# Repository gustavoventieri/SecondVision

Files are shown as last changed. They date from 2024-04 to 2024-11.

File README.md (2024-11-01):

<h1 align="center"> Second Vision </h1> <br>
<p align="center">
  <a href="https://github.com/gustavoventieri/SecondVision">
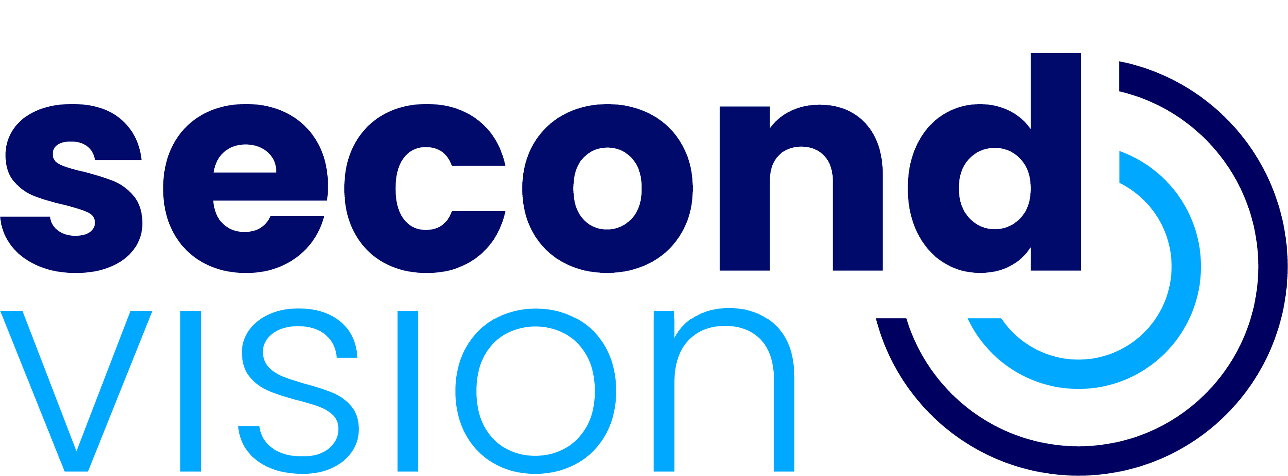
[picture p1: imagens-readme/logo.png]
Second Vision Logo GitPoint
    
  </a>
</p>

<p align="center">
  Second Vision, uma nova forma de enxergar o mundo para aqueles que não o podem ver.
</p>

## Tabela de Conteúdos

- [Introdução](#Introdução)
- [Documentação](#Documentação)
- [Desenvolvedores](#Desenvolvedores)

## Introdução

Este repositório contém o código e a documentação do Trabalho de Conclusão de Curso (TCC) dos alunos da ETEC da Zona Leste. Esse TCC consiste em um dispositivo de microcomputador projetado para auxiliar deficientes visuais na detecção de objetos potencialmente perigosos no ambiente metropolitano.

O dispositivo utiliza uma câmera integrada para capturar imagens do ambiente ao redor do usuário e, em seguida, processa essas imagens em tempo real para identificar objetos potencialmente perigosos, como obstáculos. Quando um objeto perigoso é detectado, o dispositivo emite alertas sonoros através de uma aplicação mobile para notificar o usuário sobre a presença do objeto.

O objetivo deste projeto é aumentar a autonomia e segurança das pessoas com deficiência visual em suas atividades diárias, proporcionando-lhes uma ferramenta acessível e eficaz para detectar e evitar obstáculos nas metrópoles.

## Documentação

Aqui estão alguns documentos construídos ao decorrer do trabalho: 

* Monografia
* Diagrama de Casos de Uso
* Diagrama de Máquina-Estado
* Diagrama de Sequência
* Diagrama de Atividade
* Wireframes
  
## Desenvolvedores

Obrigado pela dedicação e foco de todos os envolvidos!

# Autores
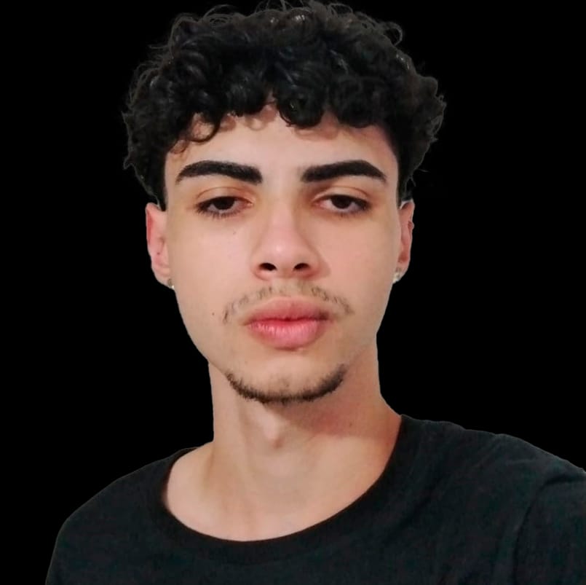
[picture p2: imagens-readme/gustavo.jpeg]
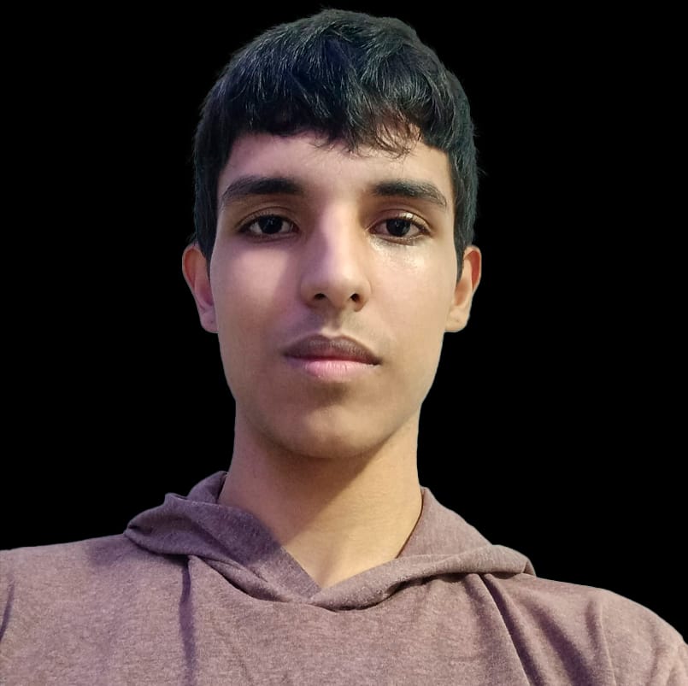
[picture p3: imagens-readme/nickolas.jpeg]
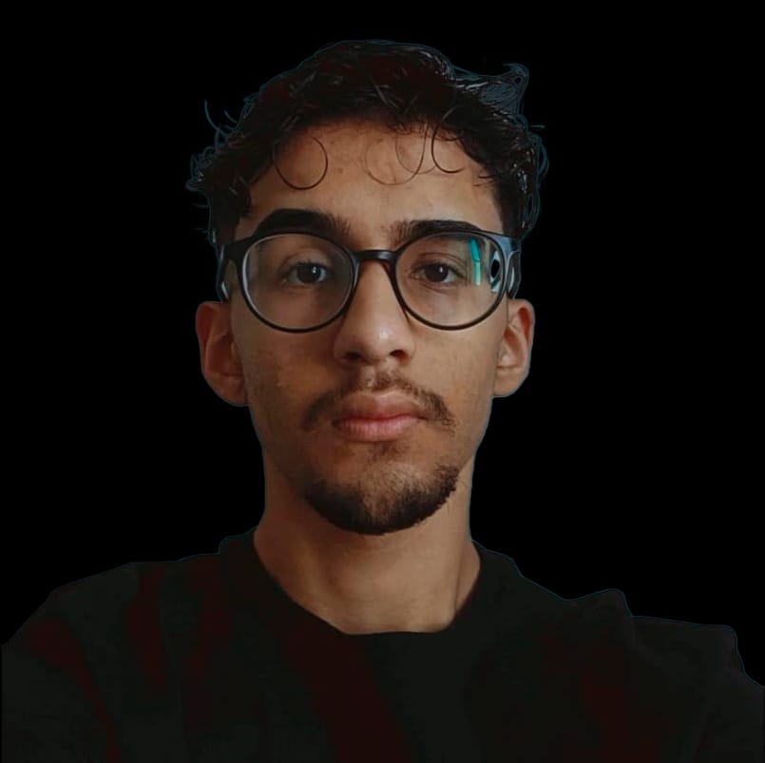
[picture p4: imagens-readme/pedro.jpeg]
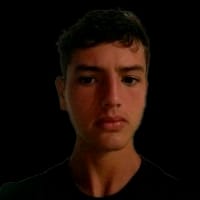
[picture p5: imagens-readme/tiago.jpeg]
| [<br><sub>Gustavo Mendes Ventieri Mariano</sub>](https://github.com/gustavoventieri/) |  [<br><sub>Nickolas Maia de Araujo</sub>](https://github.com/nickolss)  |  [<br><sub>Pedro Fernandes Araújo</sub>](https://github.com/PedroFAraujo) | [<br><sub>Tiago Bryan Ramos de Oliveira</sub>](https://github.com/TiagoBryan) | 
| :---: | :---: | :---: | :---: |

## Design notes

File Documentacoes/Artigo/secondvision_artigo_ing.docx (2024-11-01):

Second Vision - Sistema para auxílio de deficientes visuais

Second Vision - System to help the visually impaired

Second Vision - Sistema de ayuda a los discapacitados visuales

Gustavo Mendes Ventieri Mariano [^1]

ventierigustavo@gmail.com

Nickolas Maia de Araujo ¹

Nickolasmaraujo@gmail.com

Pedro Fernandes Araújo¹

pedrofeearaujo@gmail.com

Tiago Bryan Ramos de Oliveira ¹

tiagobryanroliveira@gmail.com

Jeferson Roberto de Lima¹

Jeferson.lima17@etec.sp.gov.br

Palavras-chave:

Sistema.

Autonomia.

Deficiência Visual.

Visão Computacional.

Keywords:

System.

Autonomy.

Visually Impaired.

Computer Vision.

Palabras clave:

Sistema.

Autonomía.

Discapacidad Visual.

Visión Por Ordenador.

Apresentado em:

05 dezembro, 2024

Evento:

7º EnGeTec

Local do evento:

Fatec Zona Leste

Avaliadores:

Avaliador 1

Avaliador 2

Resumo:

Este trabalho apresenta um sistema que auxilia a autonomia e inclusão de pessoas com deficiência visual. Por meio da tecnologia vestível e da visão computacional, o sistema oferece uma gama de funcionalidades que podem auxiliar a locomoção. O objetivo principal é promover a inclusão social e melhorar a qualidade de vida dessa parcela da população, que enfrenta sérios desafios e desigualdades, mesmo com os benefícios legais. A pesquisa foi baseada em estudo quali-quantitativo para identificar as principais dificuldades dos deficientes visuais. O sistema abarca um IoT para a captação de objetos possivelmente perigosos e textos em placas estáticas em um software para gerar a saída dessa detecção em áudio. Espera-se que o sistema proposto tenha um impacto positivo na vida dessas pessoas, reduzindo o número de acidentes, melhorando a saúde física, mental e autoestima, promovendo a inserção comunitária e, por fim, elevando a qualidade de vida. Conclui-se que, por meio desse trabalho, o público-alvo consiga uma melhora na condição de vida, beneficiando-se de um possível ganho de autonomia para atenuar a marginalização desse grupo.

Abstract:

This paper presents a system that aids the autonomy and inclusion of visually impaired people. Using wearable technology and computer vision, the system offers a range of functionalities that can help people get around. The main objective is to promote social inclusion and improve the quality of life of this section of the population, which faces serious challenges and inequalities, even with legal benefits. The research was based on a qualitative-quantitative study to identify the main difficulties faced by the visually impaired. The system includes an IoT to capture possibly dangerous objects and texts on static signs and software to generate audio output from this detection. It is hoped that the proposed system will have a positive impact on the lives of these people, reducing the number of accidents, improving their physical and mental health and self-esteem, promoting community integration, and, ultimately, raising their quality of life. It is concluded that, through this work, the target audience will achieve an improvement in their living conditions, benefiting from a possible gain in autonomy to mitigate the marginalization of this group.

Resumen:

Este trabajo presenta un sistema que ayuda a la autonomía e inclusión de personas con discapacidad visual. A través de tecnología wearable y visión por computador, el sistema ofrece una serie de funcionalidades que pueden ayudar a la locomoción. El objetivo principal es promover la inclusión social y mejorar la calidad de vida de este sector de la población, que se enfrenta a graves desafíos y desigualdades, incluso con beneficios legales. La investigación se basó en un estudio cualitativo-cuantitativo para identificar las principales dificultades a las que se enfrentan las personas con discapacidad visual. El sistema incluye un IOT para detectar objetos y textos posiblemente peligrosos en señales estáticas y un software para generar una salida de audio a partir de esta detección. Se espera que el sistema propuesto tenga un impacto positivo en la vida de estas personas, reduciendo el número de accidentes, mejorando su salud física y mental y su autoestima, promoviendo la integración en la comunidad y, en definitiva, aumentando su calidad de vida. Se concluye que, a través de este trabajo, el público objetivo conseguirá una mejora en sus condiciones de vida, beneficiándose de una posible ganancia de autonomía que mitigue la marginación de este colectivo.

# 1. Introduction

The visually impaired are all those with total or partial loss of sight, making up a significant portion of the Brazilian population (ALVES; DUARTE, 2008), approximately 8.9% of citizens (PNAD CONTÍNUA, 2022). As a result of this condition, they face psychological, social and economic problems, resulting in loss of self-esteem, status, occupational restrictions and reduced income (FILHO, 2012). As a result, this study aims to restore some of the autonomy of the visually impaired, provide a comprehensive form of personal prevention and improve the psychological and economic aspects of those affected by visual impairment.

Furthermore, assistive technologies do not come at an inclusive price for people with visual impairments, and due to their high cost, a portion of the population is neglected and silenced (G1, 2022). As a result, digital inclusion is needed to encourage the exercise of citizenship through technology (FILHO, 2003 apud SAMPAIO, 2006).

Given this scenario, documentation was developed based on use-case, sequence, activity and state-machine diagrams to structure the project, facilitating its effective development and maintenance, if necessary. Using an assistive technology to help the visually impaired to be autonomous in cities, based on computer vision for the analysis of static texts and potentially dangerous objects catalogued on the basis of models pre-established by the YOLOv8 artificial neural network, and qualitative and quantitative research and a bibliographic survey, software was developed to process the data detected using the Raspberry Pi 5 microcomputer integrated with the Python programming language and the OpenCV and Pytesseract libraries. The verified data is sent to the visually impaired person via a multiplatform mobile application developed in React Native and paired with the microcomputer via Bluetooth.

Subsequent chapters will present all the stages in the process of building the Second Vision - Autonomy Aid System for the Visually Impaired in the Metropolis project - comprising the theoretical framework, method, final considerations and references, with argumentative support given to the project by the company Meta on React Native technology, Van Rossum, creator of the Python programming language and Lakatos and Marconi on the research methodologies used.

2. Theoretical Foundation

In this section, introduce the main concepts and used technologies that underpin our theoretical foundation for the Second Vision development.

## 2.1. Visually Impaired

Around 285 million people have some degree of visual impairment, of which approximately 40 million are totally blind (World Health Organization, 2023). These figures highlight the significant proportion of the global population facing this condition. Furthermore, it is essential to prioritize the health and well-being of the entire population, highlighting the importance of meeting the needs of this significant portion of society (Sustainable Development Goals, 2024).

## 2.2. Computer Vision

Computer vision is conceived as a set of responsible methods and destined for machine vision when acquiring, processing, analyzing and interpreting data from the environment, allowing it to manipulate and recognize objects (FÖRSTNER; WROBEL, 2016). The artificial procedures that make computer vision suitable are image processing and pattern recognition (KLETTE, 2014). Moreover, computer vision establishes semantic descriptions of images, assigning them interpretations and classifying them into equivalent sets by identifying similar features (KHAN et al., 2018).

## 2.3. Raspberry PI 5

The Raspberry Pi, created by the Raspberry Pi company in 2012, is a low-cost microcomputer and consequently began to be widely used for automation in everyday life (OLIVEIRA; NABARRO; ZANETTI, 2018).

According to figure one, The Raspberry PI 5 has a processing power of 2.4GHz, Random Access Memory (RAM) memory capacity of up to 8GB, four Universal Serial Bus (USB) ports, and connection with the internet (OFFICIAL RASPBERRY PI DOCUMENTATION, 2024).

The microcomputer will be used within the context of the project to process the object and text information coming from the camera, allowing the recognition of these detectable objects and the effective operation of the system without the intervention of cloud processing, facilitating the use of Second Vision in remote locations that do not have access to a quality signal.

## 2.4. Python

The Python programming language is a general-purpose language with a focus on high readability and multi-paradigm, providing developers with greater productivity (VAN ROSSUM, 2007).

In addition, due to a programming language with a low learning curve and available for the most diverse operating systems, Python has become an essential technology for the development of large and scalable systems (LUTZ, 2001).

The Python language is used to implement the Generic Attribute Profile (GATT) server, which handles all the information coming from the camera, from its processing to its return for use by the mobile application.

## 2.5. Open Source Computer Vision Library (OpenCV)

OpenCV, developed by Intel Corporation, is an open source library and multiplatform, created to facilitate the users access and the developers access to multiplatform computer vision (MARENGONI; STRINGHINI, 2009).

The aim of the OpenCV library is to provide tools for developing applications aimed at image processing, visual data analysis, data structure, camera calibration, object recognition, motion analysis (tracking) and image labeling (BRADSKI; KAEHLER, 2008).

The use of the OpenCV library allows computer vision to be implemented within the system, simplifying and facilitating image processing and detection through functions such as grayscale, which transforms the colors of the image to grayscale, preserving the light intensity data and excluding the color values.

## 2.6. You Only Look Once (YOLO)

YOLO is a model for detecting and classifying objects and segmenting images in real time. Its algorithm is characterized by its fast calculation speed and the small size of the detection model (JIANG et al., 2022). By sectioning the image into grids, YOLO simultaneously calculates the predictions of the bounding boxes and classes, defining the probability of there being an object in each bounding box (HUANG; PEDOEEM; CHEN, 2018). In addition, YOLO technology has a rapid ability to identify and track vehicles, bicycles, people and other obstacles found in metropolises, exacerbating security (TERVEN; CÓRDOVA-ESPARZA; ROMERO-GONZÁLEZ, 2023).

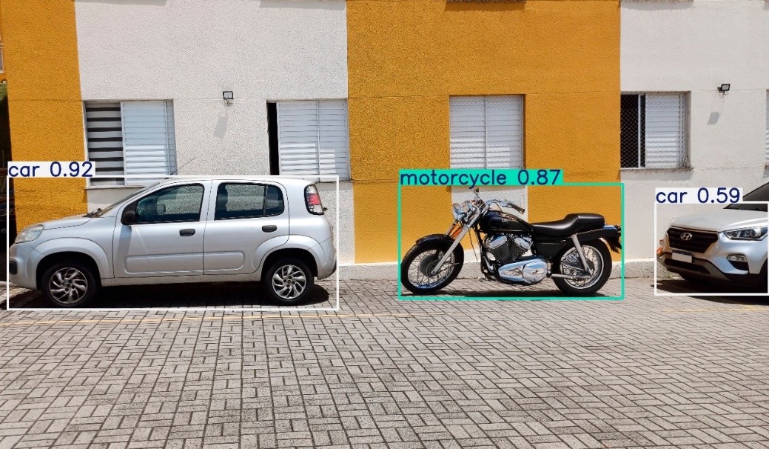
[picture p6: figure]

Source: Authors (2024).

Figure 1 - Yolo working example.

The YOLO technology, as shown in Figure 1, was used within the project for the detection and recognition of potentially dangerous objects pertinent to the Second Vision context and, due to its pre-trained models with an expressive processing speed, it was used.

## 2.7. Pytesseract

Tesseract is an open source optical character recognition engine that is the simplest way to convert typed, handwritten or printed text contained in images into digitally manipulable text (AKHIL, 2016). Furthermore, this mechanism is like the combination of eye and brain, as the eye receives the image as input and the brain processes and interprets the nuances of this image, but Tesseract only deals with text processing (PATEL, 2012).

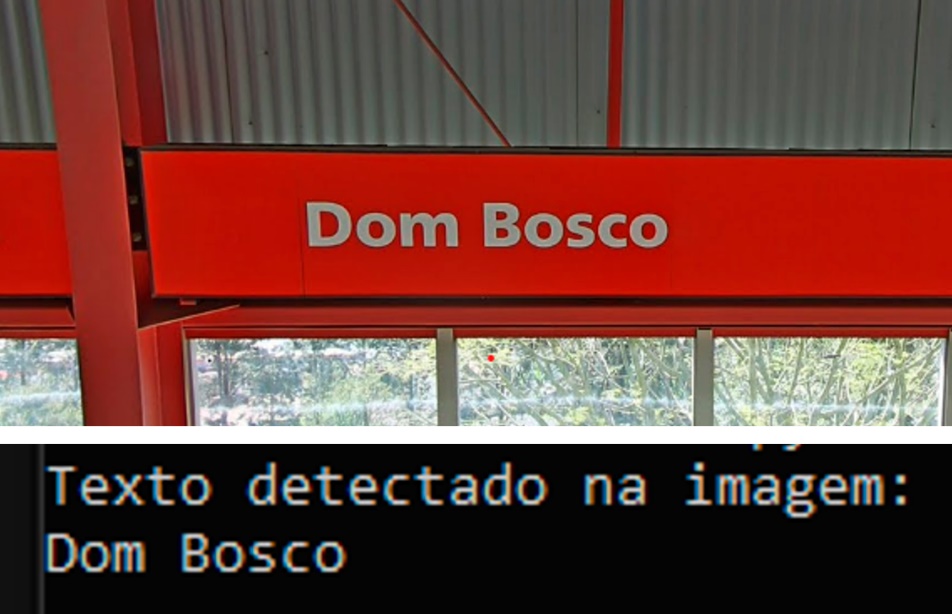
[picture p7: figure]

Python-Tesseract (Pytesseract) is an adaptation of the open source Tesseract library to work as a feature in the Python programming language, capable of recognizing and extracting text from scanned formats using this optical procedure of Tesseract (JAYOMA, 2020).

Figure 2 - Pytesseract working example

Source: Authors (2024).

Pytesseract, as shown in figure 2, is used to detect static texts, configured to recognize only texts from the Latin alphabet and to improve the accuracy of the words detected, thus helping the visually impaired to be more autonomous in urban environments.

## 2.8. React Native

React, Facebook's JavaScript library, is based on components and is responsible for structuring and pre-configuring visual elements. Its innovation lies in not having to perform micro-operations to modify the content of a component, making User Interface (UI) development possible (BODUCH, 2017).

In addition, React Native is a framework for producing multiplatform mobile applications that look “native”, structured in React (EISENMAN, 2015). In addition, React Native is developed solely in Javascript or Typescript, but the interface components are generated natively, allowing the Application Programming Interfaces (APIs) of the platforms of the respective devices to be used, thus creating a layer of abstraction (META, 2024).

The React Native framework is used throughout the development of the mobile application, responsible for reproducing the information detected from the GATT server. This technology was used to reach a wider audience due to its ability to generate cross-platform mobile applications.

# 3. Methods

The research method used is exploratory research, which is a type of scientific investigation that aims to examine a problem situation in order to enable an understanding of the problem, as well as to formulate initial perceptions and hypotheses (LAKATOS; MARCONI, 1999). In this way, exploratory research, using a bibliographic survey, qualitative and quantitative approaches, allows us to explore the particularities experienced by the visually impaired, resulting in a greater general understanding of the needs and difficulties they face.

As for the bibliographic survey, it corresponds to scientific productions and data collection based mainly on scientific articles, books, magazines, encyclopedias and critical essays; as for the qualitative approach, it refers to the interpretation of the information of the object of study, as well as understanding their opinions and attitudes, structuring itself on the existence or non-existence of attributes; the quantitative approach, in turn, refers to statistics, numbers and percentages, which allow researchers to quantify and evaluate the object of study (LAKATOS; MARCONI, 1999).

In the Second Vision project, the bibliographic survey allows for the analysis and review of productions related to the problems and technologies used in the construction of the project, enabling researchers to become proficient in the topics in question. With regard to the qualitative approach, it focuses on the specific perception of the needs, experiences and challenges of the visually impaired in urban environments, in line with understanding the main obstacles they face in metropolises and how a system could help improve their autonomy. As far as the quantitative approach is concerned, it is intended to measure the main objects found in metropolises that can compromise the autonomy of the visually impaired, analogously to considering statistical analyses of the effectiveness of recognizing potentially dangerous objects and reading the texts on static signs, as well as the system's performance when carrying out these functions. As a result, it is stated that by integrating a bibliographic survey with a qualitative and quantitative approach, a greater understanding of the problems and needs faced by the visually impaired can be achieved, as well as the development of solutions that can contribute to user-centered accessibility.

# 4. Results and Discussions

The project achieves a capacity to promote inclusion and accessibility in terms of urban autonomy for the visually impaired, characterizing an innovative idea with its due pertinence when pragmatizing an equity, it is manifested that the system manages to satisfactorily identify the objects, despite the limitations in their variety, in addition to the wearable attribute making it simple to use, the application shaped in User Experience (UX) added to its structure with support for screen reading technologies that guides and allows the visually impaired to move the cell phone, demonstrates its aptitude in dealing with the particularities of the persona objectified.

In addition, as an artificial intelligence (AI) model is used that has parameters limited to the needs of YOLO, not adapting to the full potential that Second Vision can achieve, this limits the ability to effectively guide the visually impaired geographically, so there are margins for a significant improvement in the nature of the system, to make it more capable in this objective through, for example, an AI model of its own and trained specifically for the purpose presented.

It can therefore be seen that the wearable attribute seems vulnerable to the climate, specifically the rain factor, so a case or structure that takes these externalities into account could improve the practicality of the system.

Finally, as time goes by, technology is exponentially evolving and becoming part of people's lives, and this integration of technology for the purpose of providing social justice is extremely pleasing. By helping with this, the system contributes to a better world that does not make people with disabilities invisible; on the contrary, it reinforces that they are also entitled to rights and deserve dignity.

## 4.1. Second Vision

Similarly to the current chapter, images and detailed descriptions that elucidate the final result of the project are shown below. This information is intended to provide a clear and comprehensive understanding of the results achieved with the Second Vision device and mobile application.

Figure 3 shows the Second Vision device, made up of the Raspberry PI 5 microcomputer connected to the Uninterruptible Power Supply (UPS), which acts as the power supply for the Raspberry PI 5 and the voltage, current and power regulator for the battery; In addition, the case created through modeling and a 3D printer to attach the Second Vision - IoT device together with the vest to make the system wearable; and the camera to detect and recognize potentially dangerous objects and read text on static signs.

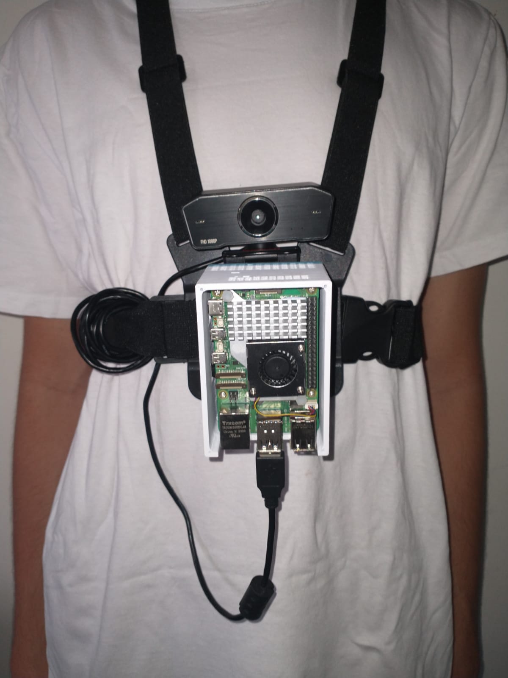
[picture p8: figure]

Figure 3 - Image of the Second Vision device

Source: Authors (2024).

Figure 4 shows the finished wearable prototype of the Second Vision system, encompassed by a stylized case adapted to protect the physical component and coupled to a wearable support that can be adjusted to different bodies, so that it brings fluidity and comfort to its use by the visually impaired, allowing them full autonomous locomotion as users of the system.

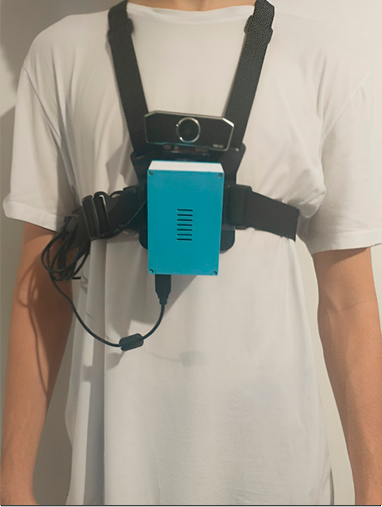
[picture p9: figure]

Source: Authors (2024).

Figure 4 - Second Vision Wearable System

Figure 5 shows the main screen of the mobile application, displayed after the visually impaired person has paired their smartphone with the Raspberry PI via Bluetooth. This screen provides information about the system, such as the amount of battery remaining, the system status, the speech interval time of the detections and the detection mode currently running, followed by a brief summary of how the chosen mode operates.

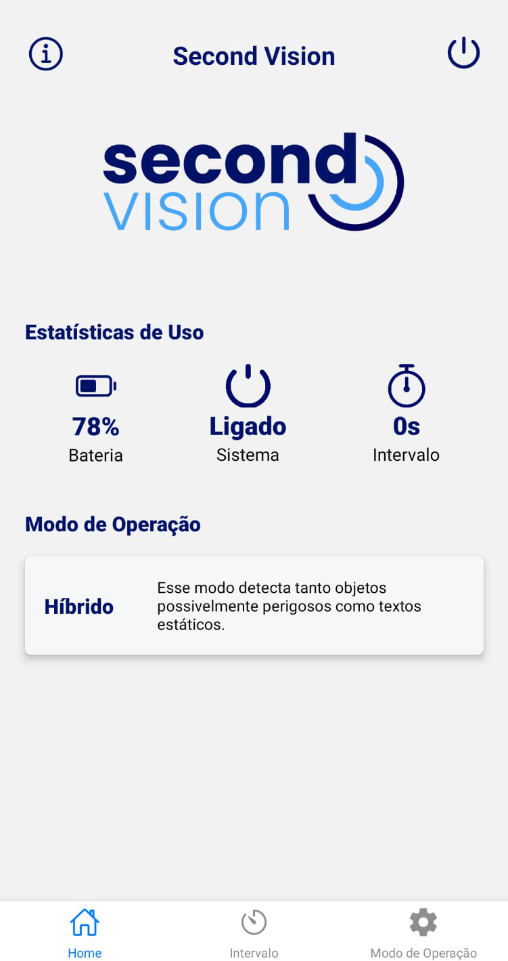
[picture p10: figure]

Source: Authors (2024).

Figure 5 - Main Application Screen

# 5. Final Considerations

The Second Vision project is a very important step towards increasing the safety and freedom of the visually impaired, as we have managed to create a tool that allows users greater autonomy and facilitates the process of getting around in metropolises with the help of an object recognition and static text reading system.

With the help of data to implement a more assertive system, we were able to demonstrate a working model using the methods presented that show the possibility of innovative approaches to a social problem.

Although the project managed to achieve its initial objectives, there is still room for expansion and improvement. The greater viability of the system could be improved by including new features, such as recognizing more complex situations and training more objects for detection using deep learning.

In short, Second Vision is not just a technological solution; it is a step towards a more accessible world where everyone can enjoy greater freedom and safety. We hope that this work will inspire new projects and research in this area, broadening the discussion on inclusion and innovation.

References

BRADSKI, Gary; KAEHLER, Adrian. Learning OpenCV: Computer vision with the OpenCV library. " O'Reilly Media, Inc.", 2008.

BODUCH, Adam. React and react native. Packt Publishing Ltd, 2017.

FÖRSTNER, Wolfgang; WROBEL, Bernhard P. Photogrammetric computer vision. Springer International Publishing Switzerland, 2016.

HUANG, Rachel; PEDOEEM, Jonathan; CHEN, Cuixian. YOLO-LITE: a real-time object detection algorithm optimized for non-GPU computers. In: 2018 IEEE international conference on big data (big data). IEEE, 2018. p. 2503-2510.

JIANG, Peiyuan et al. A Review of Yolo algorithm developments. Procedia computer science, v. 199, p. 1066-1073, 2022.

KHAN, Salman et al. A guide to convolutional neural networks for computer vision. 2018.

KLETTE, Reinhard. Concise computer vision. London: Springer, 2014.

LUTZ, Mark. Programming python. " O'Reilly Media, Inc.", 2001.

META - React Native, 2024. Disponível em: https://reactnative.dev/docs/environment-setup. Acesso em: 11 setembro 2024

EISENMAN, Bonnie. Learning react native: Building native mobile apps with JavaScript. " O'Reilly Media, Inc.", 2015.

AKHIL, S. An overview of tesseract OCR engine. In: A seminar report. Department of Computer Science and Engineering National Institute of Technology, Calicut Monsoon. 2016.

PATEL, Chirag; PATEL, Atul; PATEL, Dharmendra. Optical character recognition by open source OCR tool tesseract: A case study. International journal of computer applications, v. 55, n. 10, p. 50-56, 2012.

JAYOMA, Jaymer M.; MOYON, Elbert S.; MORALES, Edsel Matt O. OCR based document archiving and indexing using PyTesseract: A record management system for dswd caraga, Philippines. In: 2020 IEEE 12th International Conference on Humanoid, Nanotechnology, Information Technology, Communication and Control, Environment, and Management (HNICEM). IEEE, 2020. p. 1-6.

OLIVEIRA; Cláudio Luis Vieira; NABARRO, Cristina Becker Matos; ZANETTI, Humberto Augusto Piovesana. Raspberry Pi Descomplicado. 1. ed. São Paulo: Saraiva Educação S.A., 2018. 224 p.

MARENGONI, Maurício; STRINGHINI, Stringhini. Tutorial: Introdução à visão computacional usando opencv. Revista de Informática Teórica e Aplicada, v. 16, n. 1, p. 125-160, 2009.

MOLINO, Monica; CORTESE, Claudio G.; GHISLIERI, Chiara. Technology acceptance and leadership 4.0: A quali-quantitative study. International Journal of Environmental Research and Public Health, v. 18, n. 20, p. 10845, 2021.

TERVEN, Juan; CÓRDOVA-ESPARZA, Diana-Margarita; ROMERO-GONZÁLEZ, Julio-Alejandro. A comprehensive review of yolo architectures in computer vision: From yolov1 to yolov8 and yolo-nas. Machine Learning and Knowledge Extraction, v. 5, n. 4, p. 1680-1716, 2023.

UNITED NATIONS. The 17 Sustainable Development Goals. Disponível em: <https://sdgs.un.org/goals>. Acesso em: 11 de setembro de 2024.

VAN ROSSUM, Guido et al. Python programming language. In: USENIX annual technical conference. 2007. p. 1-36.

STOCKEMER, Daniel; STOCKEMER, Glaeser; GLAESER, J. Quantitative methods for the social sciences. Cham, Switzerland: Springer International Publishing, 2019.

WORLD HEALTH ORGANIZATION. Blindness and vision impairment. Disponível em: <https://www.who.int/news-room/fact-sheets/detail/blindness-and-visual-impairment>. Acesso em: 11 de setembro de 2024.

RASPBERRY PI, Raspberry Pi Hardware. Disponível em: <https://www.raspberrypi.com/documentation/computers/raspberry-pi.html>. Acesso em: 11 de setembro de 2024.

“The author(s) of the work declare(s) that no Artificial Intelligence (AI) tool/service was used during the preparation of the manuscript, and that all the text was produced and is the responsibility of the authors.”

[^1] Etec da Zona Leste

Faculdade de Tecnologia da Zona Leste | Fatec Zona Leste 7º EnGeTec | 2024 7°Encontro de Gestão e Tecnologia ISSN 2675-4479 Governança, Tecnologia e Economia Circular Dezembro de 2024

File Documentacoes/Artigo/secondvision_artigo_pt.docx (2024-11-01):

Second Vision - Sistema para auxílio de deficientes visuais

Second Vision - System to help the visually impaired

Second Vision - Sistema de ayuda a los discapacitados visuales

Gustavo Mendes Ventieri Mariano [^1]

ventierigustavo@gmail.com

Nickolas Maia de Araujo ¹

Nickolasmaraujo@gmail.com

Pedro Fernandes Araújo¹

pedrofeearaujo@gmail.com

Tiago Bryan Ramos de Oliveira ¹

tiagobryanroliveira@gmail.com

Jeferson Roberto de Lima¹

Jeferson.lima17@etec.sp.gov.br

Palavras-chave:

Sistema.

Autonomia.

Deficiência Visual.

Visão Computacional.

Keywords:

System.

Autonomy.

Visually Impaired.

Computer Vision.

Palabras clave:

Sistema.

Autonomía.

Discapacidad Visual.

Visión Por Ordenador.

Apresentado em:

05 dezembro, 2024

Evento:

7º EnGeTec

Local do evento:

Fatec Zona Leste

Avaliadores:

Avaliador 1

Avaliador 2

Resumo:

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

Abstract:

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

Resumen:

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

1. Introdução

Os deficientes visuais são todos aqueles com perda total ou parcial da visão, constituindo uma parcela importante da população brasileira (ALVES; DUARTE, 2008), aproximadamente 8,9% dos cidadãos (PNAD CONTÍNUA, 2022). Em decorrência dessa condição, eles enfrentam problemas psicológicos, sociais e econômicos, resultando em perda de autoestima, status, restrições ocupacionais e diminuição de renda (FILHO, 2012). Em razão disso, o presente estudo desenvolvido visa recuperar parte da autonomia do deficiente visual, guarnecer uma forma íntegra de prevenção pessoal e melhorar aspectos psicológicos e econômicos do afetado pela deficiência visual.

Ademais, as tecnologias assistivas possuem um preço não inclusivo para pessoas com deficiência visual, devido ao seu alto custo há uma parcela da população sendo negligenciada e silenciada (G1, 2022). Em virtude disso, é necessária uma inclusão digital para fomentar o exercício da cidadania por intermédio da tecnologia (FILHO, 2003 apud SAMPAIO, 2006).

Diante desse cenário, foi desenvolvida a documentação embasando-se nos diagramas de caso de uso, sequência, atividade e máquina-estado para a estruturação do projeto, facilitando em seu efetivo desenvolvimento e manutenção, caso necessário. Mediante uma tecnologia assistiva, para auxiliar a autonomia de deficientes visuais nas metrópoles, fundamentada na visão computacional para a análise de textos estáticos e objetos potencialmente perigosos catalogados com base nos modelos pré-estabelecidos pela rede neural artificial do YOLOv8, e por pesquisas quali-quantitativas e levantamento bibliográfico, desenvolveu-se um software para processar os dados detectados utilizando o microcomputador Raspberry Pi 5 integrado a linguagem de programação Python e as bibliotecas OpenCV e Pytesseract. Os dados verificados são informados ao deficiente visual por intermédio da aplicação móvel multiplataforma desenvolvida em React Native emparelhada ao microcomputador por Bluetooth.

Nos capítulos subsequentes, serão apresentadas todas as etapas do processo de construção do projeto Second Vision – Sistema De Auxílio Na Autonomia De Deficientes Visuais Nas Metrópoles – composto pelo referencial teórico, método, considerações finais e referências, com embasamento argumentativo dado ao projeto pela empresa Meta acerca da tecnologia React Native, de Van Rossum, criador da linguagem de programação Python e de Lakatos e Marconi sobre as metodologias de pesquisa utilizadas.

2. Referencial Teórico

Na presente seção apresentam-se os principais conceitos e tecnologias utilizadas que fundamentam a base teórica do trabalho para o desenvolvimento do Second Vision.

  2.1. Deficientes Visuais

Cerca de 285 milhões de pessoas apresentam algum grau de deficiência visual, sendo aproximadamente 40 milhões são totalmente cegas (Organização Mundial da Saúde, 2023). Esses números ressaltam a significativa proporção da população global que enfrenta essa condição. Além disso, é essencial priorizar a saúde e o bem-estar de toda a população, destacando a importância de atender às necessidades dessa parcela expressiva da sociedade (Objetivos de Desenvolvimento Sustentável, 2024).

  2.2. Visão Computacional

Visão Computacional é concebida como um conjunto de métodos responsáveis e destinados pela visão de máquinas ao adquirir, processar, analisar e interpretar dados provenientes do ambiente, possibilitando manipular e reconhecer objetos (FÖRSTNER; WROBEL, 2016). Os procedimentos artificiais que dão aptidão à visão computacional são: processamento de imagens e reconhecimento de padrões (KLETTE, 2014). Ademais, a visão computacional estabelece descrições semânticas das imagens, atribuindo-as a interpretações e classificando-as em conjuntos equivalentes ao identificar particularidades semelhantes (KHAN et al., 2018).

  2.3. Raspberry PI 5

O Raspberry PI, criado pela empresa Raspberry Pi em 2012, é um microcomputador de custo reduzido, consequentemente, começou a ser amplamente empregado para automações no cotidiano (OLIVEIRA; NABARRO; ZANETTI, 2018).

O Raspberry PI 5 tem o potencial de processamento de 2.4GHz, capacidade de memória Random Acess Memory (RAM) de até 8GB, quatro portas Universial Serial Bus (USB) e com conexão à internet (RASPBERRY PI, 2024).

O microcomputador será utilizado dentro do contexto do projeto para processar as informações de objetos e textos vindas da câmera, permitindo o reconhecimento desses objetos detectáveis e o efetivo funcionamento do sistema sem a intervenção de um processamento em nuvem, facilitando a utilização do Second Vision em locais remotos que não possuem acesso a um sinal de qualidade.

  2.4. Python

A linguagem de programação Python é uma linguagem de propósito geral com foco em alta legibilidade e multiparadigma, proporcionando ao desenvolvedor uma maior produtividade (VAN ROSSUM, 2007).

Ademais, junto com uma linguagem de baixa curva de aprendizado e disponível para os mais diversos sistemas operacionais, o Python torna-se uma tecnologia essencial para o desenvolvimento de sistemas de grande porte e escalabilidade (LUTZ, 2001).

A linguagem Python é utilizada para a implementação do servidor Generic Attribute Profile (GATT), que lida com todas as informações vindas da câmera, desde seu processamento até o retorno para ser utilizado pela aplicação mobile.

  2.5. Open Source Computer Vision Library (OpenCV)

A OpenCV, desenvolvida pela Intel Corporation, é uma biblioteca de código aberto e multiplataforma, criada para facilitar o acesso de usuários e desenvolvedores à visão computacional (MARENGONI; STRINGHINI, 2009).

O objetivo da biblioteca OpenCV é fornecer ferramentas para o desenvolvimento de aplicações voltadas ao processamento de imagem, análise de dados visuais, estrutura de dados, calibração de câmera, reconhecimento de objetos, análise de movimento (rastreamento) e rotulagem de imagem (BRADSKI; KAEHLER, 2008).

O uso da biblioteca OpenCV permite a implementação da visão computacional dentro do sistema, simplificando e facilitando o processamento e detecção da imagem por meio de funções como grayscale, que transforma as cores da imagem para escala de cinza, conservando os dados da intensidade de luz e excluindo os valores das cores.

  2.6. You Only Look Once (YOLO)

YOLO é um modelo de detecção e classificação de objetos, e segmentação de imagens em tempo real, seu algoritmo é caracterizado pela rápida velocidade de cálculo e tamanho reduzido do modelo de detecção (JIANG et al., 2022). YOLO, ao seccionar a imagem em grids, calcula simultaneamente as previsões das caixas delimitadoras e das classes, definindo a probabilidade de haver um objeto em cada caixa delimitadora (HUANG; PEDOEEM; CHEN, 2018). Ademais, a tecnologia YOLO possui uma capacidade rápida de identificação e rastreamento de veículos, bicicletas, pessoas e outros obstáculos encontrados em metrópoles, exacerbando a segurança (TERVEN; CÓRDOVA-ESPARZA; ROMERO-GONZÁLEZ, 2023).

Figura 1 - Exemplo funcionamento YOLO


Fonte: Autoria Própria (2024).

A tecnologia YOLO, como demonstrado na Figura 1, foi empregada dentro do projeto para a detecção e reconhecimento de objetos potencialmente perigosos pertinentes ao contexto do Second Vision e, devido a seus modelos pré-treinados com uma velocidade de processamento expressiva, foi utilizada.

  2.7. Pytesseract

Tesseract é um mecanismo de reconhecimento óptico de caracteres de código aberto, sendo a forma mais simples de converter textos digitados, manuscritos ou impressos contidos em imagens para um texto manipulável digitalmente (AKHIL, 2016). Ademais, esse mecanismo é como a combinação entre olho e cérebro, pois o olho recebe como entrada a imagem e o cérebro processa e interpreta as nuances dessa imagem, mas o Tesseract aborda apenas o processamento de textos (PATEL, 2012).

Por conseguinte, o Python-Tesseract (Pytesseract), é a adaptação da biblioteca de código aberto Tesseract para o funcionamento como um feature na linguagem de programação Python, capaz de reconhecer e extrair textos de formatos digitalizados por meio do procedimento óptico do Tesseract (JAYOMA, 2020).

Figura 2 - Exemplo funcionamento Pytesseract


Fonte: Autoria Própria, (2024).

O Pytesseract, como visualizado na figura 2, é utilizado para a detecção de textos estáticos, configurado para o reconhecimento apenas de textos do alfabeto latino e para aperfeiçoar a acurácia das palavras detectadas, destarte, há um maior auxílio na autonomia dos deficientes visuais em ambientes urbanos.

  2.8. React Native

React, Facebook's React, biblioteca JavaScript do Facebook, é baseado em componentes, sendo responsável pela estruturação e pré configuração dos elementos visuais, sua inovação está em não precisar realizar microoperações para modificar o conteúdo de um componente, viabilizando o desenvolvimento da interface do usuário (UI) (BODUCH, 2017).

Ademais, o React Native é um framework para produção de aplicações móveis multiplataforma, que pareçam “nativas”, estruturado no React (EISENMAN, 2015). Ademais, o React Native é desenvolvido unicamente em Javascript ou Typescript, entretanto os componentes da interface são gerados de forma nativa, permitindo que as Application Programming Interfaces (APIs) das plataformas dos respectivos dispositivos sejam utilizadas, criando assim uma camada de abstração (META, 2024).

O framework React Native é utilizado para todo o desenvolvimento da aplicação mobile, responsável por reproduzir as informações detectadas provindas do servidor GATT. Essa tecnologia foi utilizada visando abranger uma maior parcela de público devido a sua capacidade de gerar aplicações mobile multiplataforma.

3. Método

O método de pesquisa utilizado classifica-se em pesquisa exploratória, tratando-se de um tipo de investigação científica que objetiva examinar uma situação problema a fim de viabilizar uma compreensão da problemática, bem como formular percepções e hipóteses iniciais (LAKATOS; MARCONI, 1999). Dessa maneira, a pesquisa exploratória, empregando de levantamento bibliográfico, abordagens qualitativas e quantitativas, permite explorar particularidades vivenciadas pelos deficientes visuais, resultando em um maior entendimento genérico sobre as necessidades e dificuldades enfrentadas pelos mesmos.

Relativo ao levantamento bibliográfico, corresponde a produções científicas e coleta de dados fundamentando-se sobretudo em artigos científicos, livros, revistas, enciclopédias e ensaios críticos; quanto a abordagem qualitativa, refere-se à interpretação das informações do objeto de estudo, assim como compreender suas opiniões e atitudes, estruturando-se na existência ou inexistência de atributos; a abordagem quantitativa, por sua vez, tange estatísticas, números e porcentagens, que permitem aos pesquisadores quantificar e avaliar o objeto de estudo (LAKATOS; MARCONI, 1999).

No projeto Second Vision, o levantamento bibliográfico permite a análise e revisão de produções relacionadas com a problemática e as tecnologias exercidas na construção do projeto, viabilizando a proficiência dos pesquisadores com os temas em questão. Em relação a abordagem qualitativa, direciona-se para a percepção específica das necessidades, experiências e desafios dos deficientes visuais em ambientes urbanos, em consonância com a compreensão dos principais obstáculos que enfrentam em metrópoles e de como um sistema poderia auxiliar a melhorar suas autonomias. No que concerne à abordagem quantitativa, destina-se a mensurar os principais objetos encontrados em metrópoles que podem comprometer a autonomia dos deficientes visuais, analogamente a ponderar análises estatísticas da eficácia do reconhecimento de objetos potencialmente perigosos e a leitura dos textos em placas estáticas, tal como o desempenho do sistema ao executar tais funções. Por conseguinte, afirma-se que ao integrar levantamento bibliográfico, integrado à abordagem quali-quantitativa, constitui-se uma maior compreensão dos problemas e necessidades enfrentadas pelos deficientes visuais, assim como a elaboração de soluções que possam contribuir para a acessibilidade centrada no usuário.

4. Resultados e Discussões

O projeto atinge uma capacidade de promover inclusão e acessibilidade no quesito da autonomia urbana para os deficientes visuais, caracterizando uma ideia inovadora com sua devida pertinência ao pragmatizar uma equidade, manifesta-se que o sistema consegue identificar satisfatoriamente os objetos, apesar das limitações na sua variedade, além do atributo vestível tornar simples seu uso, o aplicativo moldado em User Experience (UX) somado a sua estrutura com suporte a tecnologias de leitura de tela que guia e permite deficientes visuais mexerem no celular, demonstra sua aptidão em lidar com as particularidades da persona objetivada.

Ademais como é utilizado um modelo de inteligência artificial (IA) que passa parâmetros limitados a necessidade do YOLO, não adaptando ao total potencial que o Second Vision pode alcançar, isso restringe a capacidade de efetivamente guiar os deficientes visuais geograficamente, portanto há margens para uma melhora significativa na natureza do sistema, para torná-lo mais capaz nesse objetivo por meio, por exemplo, de um modelo de IA próprio e treinado especificamente para o proposito apresentado.

Por conseguinte, percebe-se que o atributo vestível parece vulnerável ao clima, especificamente pelo fator chuva, portanto uma case ou estrutura que pondere essas externalidades podem aperfeiçoar a praticidade do sistema.

Por fim, a tecnologia com o passar do tempo está exponencialmente evoluindo e fazendo parte da vida das pessoas e é extremamente aprazível essa integração da tecnologia para fins de proporcionar justiça social, o sistema ao ajudar com essa finalidade contribui para um mundo melhor, que não invisibiliza pessoas com deficiência, pelo contrário, reforça que também são passiveis de direito e merecem dignidade.

  4.1. Second Vision

Analogamente apresentado no atual capítulo, são demonstradas abaixo imagens e descrições detalhadas que elucidam o resultado final da realização do projeto. Essa informação tem como objetivo proporcionar uma compreensão clara e abrangente dos resultados alcançados do dispositivo Second Vision e a aplicação móvel.


A figura 3 corresponde ao dispositivo Second Vision, constituído pelo microcomputador Raspberry PI 5 conectado à Uninterruptible Power Supply (UPS), tangendo uma fonte de alimentação ininterrupta, atua como o fornecedor de energia elétrica ao Raspberry PI 5 e regulador de tensão, corrente e potência da bateria; Ademais, a case criada por meio da modelagem e impressora 3D para acoplar o dispositivo Second Vision – IoT em conjunto com o colete para tornar o sistema vestível; Outrossim, a câmera para efetivar a detecção e reconhecimento dos objetos potencialmente perigosos e a leitura de textos em placas estáticas.

Figura 3 - Imagem do Dispositivo Second Vision

Fonte: Autoria Própria, (2024).

A figura 4 representa o protótipo vestível finalizado do sistema Second Vision, abarcado por uma case estilizada e adaptada para a proteção do componente físico e acoplada a um suporte vestível e ajustável a diferentes corpos, de modo que traga fluidez e conforto no seu uso por parte dos deficientes visuais, possibilitando-os a plena locomoção autonômica enquanto usuário do sistema.


Figura 4 - Sistema Vestível Second Vision

Fonte: Autoria Própria, (2024).

A figura 5 é caracterizada pela tela principal da aplicação móvel, exibida após o deficiente visual emparelhar seu smartphone com o Raspberry PI por meio do Bluetooth. Nessa tela há disponibilizado informações sobre o sistema, como a quantidade de bateria restante, o status do sistema, o tempo de intervalo de fala das detecções e o modo de detecção funcionando no momento, seguido de um breve resumo sobre como opera o modo escolhido.


Fonte: Autoria Própria, (2024).

Figura 5 - Tela Principal do Aplicativo

5. Considerações Finais

O projeto Second Vision é um passo muito importante para aumentar a segurança e a liberdade dos deficientes visuais, pois conseguimos criar uma ferramenta que permite aos usuários uma maior autonomia e facilita o processo de locomoção em metrópoles com a ajuda de um sistema de reconhecimento de objetos e leitura de textos estáticos.

Com a ajuda dos dados para implementar um sistema mais assertivo, conseguimos demonstrar um modelo de trabalho usando os métodos apresentados que mostram a possibilidade de abordagens inovadoras para um problema social.

Embora o projeto tenha conseguido atingir seus objetivos iniciais, ainda há espaço para expansão e aprimoramento. A maior viabilidade do sistema poderia ser melhorada com a inclusão de novos recursos, como o reconhecimento de situações mais complexas e o treinamento de mais objetos para a detecção, utilizando de deep learning.

Em suma, o Second Vision não é apenas uma solução tecnológica, é um passo em direção a um mundo mais acessível, onde todos possam desfrutar de maior liberdade e segurança. Esperamos que este trabalho inspire novos projetos e pesquisas nessa área, ampliando a discussão sobre inclusão e inovação.

Referências

AKHIL, S. An overview of tesseract OCR engine. In: A seminar report. Department of Computer Science and Engineering National Institute of Technology, Calicut Monsoon. 2016.

ALVES, Maria Luíza Tanure; DUARTE, Edison. Imagem corporal e deficiência visual: um estudo bibliográfico das relações entre a cegueira e o desenvolvimento da imagem corporal. 2008. Acta Scientiarum. Human and Social Sciences, 30(2), 147-154. Dissertação (Programa de Pós-Graduação em Educação Física) – Universidade Estadual de Maringá, Paraná, 2008.

BODUCH, Adam. React and react native. Packt Publishing Ltd, 2017.

BRADSKI, Gary; KAEHLER, Adrian. Learning OpenCV: Computer vision with the OpenCV library. " O'Reilly Media, Inc.", 2008.

Pesquisa Nacional por Amostra de Domicílios Contínua : pessoas com deficiência : 2022; PNAD contínua : pessoas com deficiência : 2022

CABRAL FILHO, Adilson Vaz et al. Sociedade e tecnologia digital: entre incluir e ser incluída. Liinc em revista, v. 2, n. 2, 2006.

EISENMAN, Bonnie. Learning react native: Building native mobile apps with JavaScript. " O'Reilly Media, Inc.", 2015.

FILHO, V. T. F. Bravo et al. Impacto do déficit visual na qualidade de vida em idosos usuários do sistema único de saúde vivendo no sertão de Pernambuco. Arquivos Brasileiros de Oftalmologia, v. 75, n. 3, p. 161–165, 2012.

FÖRSTNER, Wolfgang; WROBEL, Bernhard P. Photogrammetric computer vision. Springer International Publishing Switzerland, 2016.

HUANG, Rachel; PEDOEEM, Jonathan; CHEN, Cuixian. YOLO-LITE: a real-time object detection algorithm optimized for non-GPU computers. In: 2018 IEEE international conference on big data (big data). IEEE, 2018. p. 2503-2510.

JAYOMA, Jaymer M.; MOYON, Elbert S.; MORALES, Edsel Matt O. OCR based document archiving and indexing using PyTesseract: A record management system for dswd caraga, Philippines. In: 2020 IEEE 12th International Conference on Humanoid, Nanotechnology, Information Technology, Communication and Control, Environment, and Management (HNICEM). IEEE, 2020. p. 1-6.

JIANG, Peiyuan et al. A Review of Yolo algorithm developments. Procedia computer science, v. 199, p. 1066-1073, 2022.

KHAN, Salman et al. A guide to convolutional neural networks for computer vision. 2018.

KLETTE, Reinhard. Concise computer vision. London: Springer, 2014.

LUTZ, Mark. Programming python. " O'Reilly Media, Inc.", 2001.

MARCONI, M. D. A. Lakatos, e. M.(1999). Técnicas de pesquisa: planejamento, e execução de pesquisas. Amostragens e técnicas de pesquisa. Elaboração, análise e interpretações de dados, v. 4.

MARENGONI, Maurício; STRINGHINI, Stringhini. Tutorial: Introdução à visão computacional usando opencv. Revista de Informática Teórica e Aplicada, v. 16, n. 1, p. 125-160, 2009.

META - React Native, 2024. Disponível em: https://reactnative.dev/docs/environment-setup. Acesso em: 11 setembro 2024

MOLINO, Monica; CORTESE, Claudio G.; GHISLIERI, Chiara. Technology acceptance and leadership 4.0: A quali-quantitative study. International Journal of Environmental Research and Public Health, v. 18, n. 20, p. 10845, 2021.

Óculos “falantes”: como um dispositivo de inteligência artificial ajuda estudantes cegos no Brasil. (2022, julho 28). G1. https://g1.globo.com/inovacao/noticia/2022/07/28/oculos-falantes-como-um-dispositivo-de-inteligencia-artificial-ajuda-estudantes-cegos-no-brasil.ghtml

OLIVEIRA; Cláudio Luis Vieira; NABARRO, Cristina Becker Matos; ZANETTI, Humberto Augusto Piovesana. Raspberry Pi Descomplicado. 1. ed. São Paulo: Saraiva Educação S.A., 2018. 224 p.

PATEL, Chirag; PATEL, Atul; PATEL, Dharmendra. Optical character recognition by open source OCR tool tesseract: A case study. International journal of computer applications, v. 55, n. 10, p. 50-56, 2012.

RASPBERRY PI, Raspberry Pi Hardware. Disponível em: <https://www.raspberrypi.com/documentation/computers/raspberry-pi.html>. Acesso em: 11 de setembro de 2024.

STOCKEMER, Daniel; STOCKEMER, Glaeser; GLAESER, J. Quantitative methods for the social sciences. Cham, Switzerland: Springer International Publishing, 2019.

TERVEN, Juan; CÓRDOVA-ESPARZA, Diana-Margarita; ROMERO-GONZÁLEZ, Julio-Alejandro. A comprehensive review of yolo architectures in computer vision: From yolov1 to yolov8 and yolo-nas. Machine Learning and Knowledge Extraction, v. 5, n. 4, p. 1680-1716, 2023.

UNITED NATIONS. The 17 Sustainable Development Goals. Disponível em: <https://sdgs.un.org/goals>. Acesso em: 11 de setembro de 2024.

VAN ROSSUM, Guido et al. Python programming language. In: USENIX annual technical conference. 2007. p. 1-36.

WORLD HEALTH ORGANIZATION. Blindness and vision impairment. Disponível em: <https://www.who.int/news-room/fact-sheets/detail/blindness-and-visual-impairment>. Acesso em: 11 de setembro de 2024.

“O(s) autor(es) do trabalho declara(m) que durante a preparação do manuscrito não foram utilizadas ferramenta/serviço de Inteligência Artificial (IA), sendo todo o texto produzido e de responsabilidade dos autores.

[^1] Etec da Zona Leste

Faculdade de Tecnologia da Zona Leste | Fatec Zona Leste 7º EnGeTec | 2024 7°Encontro de Gestão e Tecnologia ISSN 2675-4479 Governança, Tecnologia e Economia Circular Dezembro de 2024

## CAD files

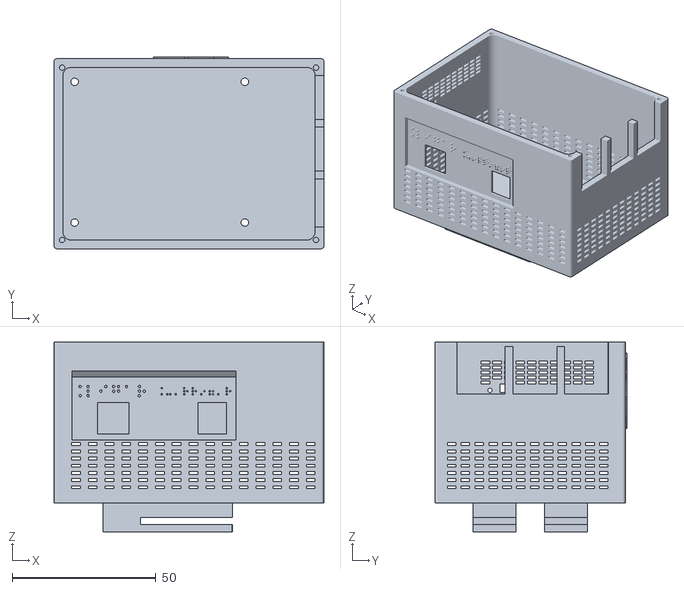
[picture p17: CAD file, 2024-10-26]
Case/CaseCorpo.stl
94.0 x 66.7 x 66.0

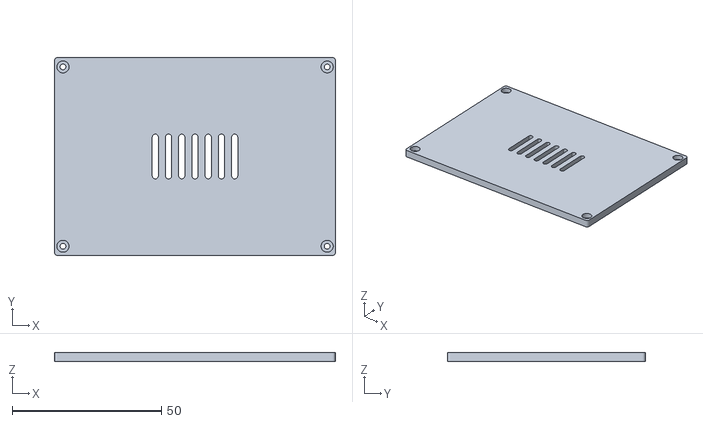
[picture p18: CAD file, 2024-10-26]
Case/TampaCase.stl
94.0 x 66.2 x 3.00

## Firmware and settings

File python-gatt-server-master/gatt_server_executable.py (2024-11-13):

from __future__ import print_function
import dbus
import dbus.exceptions
import dbus.mainloop.glib
import dbus.service
import array
import sys
import gi

try:
    from gi.repository import GLib
except ImportError:
    print("Erro ao importar o GLib")
import advertising
import gatt_server
import argparse
import threading
from gatt_server import INA219  # Esta importação pode ser removida se não for usada diretamente

# Importações adicionais para YOLO e PyTesseract
import cv2
from ultralytics import YOLO
import pytesseract
import time
from collections import deque
from spellchecker import SpellChecker

spell = SpellChecker(language='pt')


class ObjectTracker:
    def __init__(self, window_size=5):
        self.history = deque(maxlen=window_size)
        self.last_announcement = {}
        self.announcement_interval = 5  # segundos

    def update(self, detections):
        self.history.append(detections)

    def should_announce(self, object_name):
        count = sum([1 for frame in self.history if object_name in frame])
        if count >= len(self.history) // 2:
            return True
        return False

    def get_announcements(self):
        current_time = time.time()
        announcements = []

        if self.history:
            current_frame = self.history[-1]
            for obj in current_frame:
                if self.should_announce(obj):
                    if obj not in self.last_announcement or (
                            current_time - self.last_announcement[obj]) > self.announcement_interval:
                        announcements.append(obj)
                        self.last_announcement[obj] = current_time

        return announcements


def correct_text(text):
    words = text.strip().split()
    corrected_words = [spell.correction(word) if spell.correction(word) else '' for word in words]

    return " ".join(filter(None, corrected_words))


def process_frame(frame, yolo_characteristic, tesseract_characteristic):
    # YOLO processing
    yolo_model = YOLO('yolov8n.pt')
    tracker = ObjectTracker()
    allowed_objects = ['person', 'bicycle', 'car', 'motorcycle', 'bus', 'train', 'truck', 'traffic light', 'stop sign', 'fire hydrant']
    translation_dict = {
        'person': 'pessoa',
        'bicycle': 'bicicleta',
        'car': 'carro',
        'motorcycle': 'moto',
        'bus': 'ônibus',
        'train': 'trem',
        'truck': 'caminhão',
        'traffic light': 'semáforo',
        'stop sign': 'placa de pare',
        'fire hydrant': 'hidrante'
    }

    results = yolo_model.predict(source=frame)
    detections = []

    for result in results:
        for box in result.boxes:
            cls_id = int(box.cls[0])
            if cls_id in result.names:
                object_name = result.names[cls_id]
                if object_name in allowed_objects:
                    translated_name = translation_dict.get(object_name, object_name)
                    detections.append(translated_name)

    tracker.update(detections)
    announcements = tracker.get_announcements()

    if announcements:
        yolo_characteristic.send_update(','.join(announcements))
        print(f"Updated GATT characteristic with: {announcements}")
    else:
        # Enviar atualização "none" se não houver detecções
        yolo_characteristic.send_update('none')
        print("Updated GATT characteristic with: 'none'")

    # PyTesseract processing
    gray = cv2.cvtColor(frame, cv2.COLOR_BGR2GRAY)
    text = pytesseract.image_to_string(gray, lang='por')
    if text.strip():
        corrected_text = correct_text(text)
        tesseract_characteristic.send_update(f'texto: {corrected_text}')
        print(f"Updated GATT characteristic with: texto: {corrected_text}")


def camera_capture_loop(yolo_characteristic, tesseract_characteristic):
    cap = cv2.VideoCapture(0)

    while True:
        ret, frame = cap.read()
        if not ret:
            break

        process_frame(frame, yolo_characteristic, tesseract_characteristic)

        time.sleep(1)

    cap.release()


def battery_monitor_loop(battery_characteristic):
    while True:
        battery_characteristic.send_battery_update()
        time.sleep(60)


def main():
    parser = argparse.ArgumentParser()
    parser.add_argument('-a', '--adapter-name', type=str, help='Adapter name', default='')
    args = parser.parse_args()
    adapter_name = args.adapter_name

    dbus.mainloop.glib.DBusGMainLoop(set_as_default=True)
    bus = dbus.SystemBus()
    mainloop = GLib.MainLoop()

    advertising.advertising_main(mainloop, bus, adapter_name)
    app = gatt_server.gatt_server_main(mainloop, bus, adapter_name)

    if not app:
        print("Aplicação GATT não foi inicializada corretamente devido a erro no INA219.")
        sys.exit(1)

    yolo_characteristic = app.services[0].characteristics[0]
    tesseract_characteristic = app.services[0].characteristics[1]
    battery_characteristic = app.services[0].characteristics[3]

    # Start camera capture loop in a separate thread
    camera_thread = threading.Thread(target=camera_capture_loop, args=(yolo_characteristic, tesseract_characteristic))
    camera_thread.start()

    # Start battery monitor loop in a separate thread
    battery_thread = threading.Thread(target=battery_monitor_loop, args=(battery_characteristic,))
    battery_thread.start()

    try:
        mainloop.run()
    except KeyboardInterrupt:
        print("Program terminated")
        camera_thread.join()
        battery_thread.join()


if __name__ == '__main__':
    main()

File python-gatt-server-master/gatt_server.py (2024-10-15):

import dbus
import dbus.exceptions
import dbus.mainloop.glib
import dbus.service
import functools
import smbus  # Use smbus2 para evitar problemas
import time
import threading
import exceptions
import adapters
import os
import uuid  # Import para gerar UUIDs únicos

BLUEZ_SERVICE_NAME = 'org.bluez'
LE_ADVERTISING_MANAGER_IFACE = 'org.bluez.LEAdvertisingManager1'
DBUS_OM_IFACE = 'org.freedesktop.DBus.ObjectManager'
DBUS_PROP_IFACE = 'org.freedesktop.DBus.Properties'

LE_ADVERTISEMENT_IFACE = 'org.bluez.LEAdvertisement1'
GATT_MANAGER_IFACE = 'org.bluez.GattManager1'
GATT_SERVICE_IFACE = 'org.bluez.GattService1'
GATT_CHRC_IFACE = 'org.bluez.GattCharacteristic1'
GATT_DESC_IFACE = 'org.bluez.GattDescriptor1'

# UPS controller
# Config Register (R/W)
_REG_CONFIG = 0x00
# SHUNT VOLTAGE REGISTER (R)
_REG_SHUNTVOLTAGE = 0x01

# BUS VOLTAGE REGISTER (R)
_REG_BUSVOLTAGE = 0x02

# POWER REGISTER (R)
_REG_POWER = 0x03

# CURRENT REGISTER (R)
_REG_CURRENT = 0x04

# CALIBRATION REGISTER (R/W)
_REG_CALIBRATION = 0x05


class BusVoltageRange:
    """Constants for ``bus_voltage_range``"""
    RANGE_16V = 0x00  # set bus voltage range to 16V
    RANGE_32V = 0x01  # set bus voltage range to 32V (default)


class Gain:
    """Constants for ``gain``"""
    DIV_1_40MV = 0x00  # shunt prog. gain set to  1, 40 mV range
    DIV_2_80MV = 0x01  # shunt prog. gain set to /2, 80 mV range
    DIV_4_160MV = 0x02  # shunt prog. gain set to /4, 160 mV range
    DIV_8_320MV = 0x03  # shunt prog. gain set to /8, 320 mV range


class ADCResolution:
    """Constants for ``bus_adc_resolution`` or ``shunt_adc_resolution``"""
    ADCRES_9BIT_1S = 0x00  # 9bit,   1 sample,     84us
    ADCRES_10BIT_1S = 0x01  # 10bit,   1 sample,    148us
    ADCRES_11BIT_1S = 0x02  # 11 bit,  1 sample,    276us
    ADCRES_12BIT_1S = 0x03  # 12 bit,  1 sample,    532us
    ADCRES_12BIT_2S = 0x09  # 12 bit,  2 samples,  1.06ms
    ADCRES_12BIT_4S = 0x0A  # 12 bit,  4 samples,  2.13ms
    ADCRES_12BIT_8S = 0x0B  # 12bit,   8 samples,  4.26ms
    ADCRES_12BIT_16S = 0x0C  # 12bit,  16 samples,  8.51ms
    ADCRES_12BIT_32S = 0x0D  # 12bit,  32 samples, 17.02ms
    ADCRES_12BIT_64S = 0x0E  # 12bit,  64 samples, 34.05ms
    ADCRES_12BIT_128S = 0x0F  # 12bit, 128 samples, 68.10ms


class Mode:
    """Constants for ``mode``"""
    POWERDOW = 0x00  # power down
    SVOLT_TRIGGERED = 0x01  # shunt voltage triggered
    BVOLT_TRIGGERED = 0x02  # bus voltage triggered
    SANDBVOLT_TRIGGERED = 0x03  # shunt and bus voltage triggered
    ADCOFF = 0x04  # ADC off
    SVOLT_CONTINUOUS = 0x05  # shunt voltage continuous
    BVOLT_CONTINUOUS = 0x06  # bus voltage continuous
    SANDBVOLT_CONTINUOUS = 0x07  # shunt and bus voltage continuous


class INA219:
    def __init__(self, i2c_bus=1, addr=0x40):
        self.bus = smbus.SMBus(i2c_bus)
        self.addr = addr

        # Set chip to known config values to start
        self._cal_value = 0
        self._current_lsb = 0
        self._power_lsb = 0
        self.set_calibration_32V_2A()

    def read(self, address):
        data = self.bus.read_i2c_block_data(self.addr, address, 2)
        return ((data[0] << 8) + data[1])

    def write(self, address, data):
        temp = [0, 0]
        temp[1] = data & 0xFF
        temp[0] = (data & 0xFF00) >> 8
        self.bus.write_i2c_block_data(self.addr, address, temp)

    def set_calibration_32V_2A(self):
        """Configures INA219 to measure up to 32V and 2A"""
        self._current_lsb = 0.1  # 100uA per bit
        self._cal_value = 4096
        self._power_lsb = 0.002  # 2mW per bit

        self.write(_REG_CALIBRATION, self._cal_value)

        self.bus_voltage_range = BusVoltageRange.RANGE_32V
        self.gain = Gain.DIV_8_320MV
        self.bus_adc_resolution = ADCResolution.ADCRES_12BIT_32S
        self.shunt_adc_resolution = ADCResolution.ADCRES_12BIT_32S
        self.mode = Mode.SANDBVOLT_CONTINUOUS

        self.config = (self.bus_voltage_range << 13) | \
                      (self.gain << 11) | \
                      (self.bus_adc_resolution << 7) | \
                      (self.shunt_adc_resolution << 3) | \
                      self.mode

        self.write(_REG_CONFIG, self.config)

    def getShuntVoltage_mV(self):
        self.write(_REG_CALIBRATION, self._cal_value)
        value = self.read(_REG_SHUNTVOLTAGE)
        if value > 32767:
            value -= 65535
        return value * 0.01

    def getBusVoltage_V(self):
        self.write(_REG_CALIBRATION, self._cal_value)
        self.read(_REG_BUSVOLTAGE)
        return (self.read(_REG_BUSVOLTAGE) >> 3) * 0.004

    def getCurrent_mA(self):
        value = self.read(_REG_CURRENT)
        if value > 32767:
            value -= 65535
        return value * self._current_lsb * -1

    def getPower_W(self):
        self.write(_REG_CALIBRATION, self._cal_value)
        value = self.read(_REG_POWER)
        if value > 32767:
            value -= 65535
        return value * self._power_lsb


try:
    ina219 = INA219(addr=0x42)
except Exception as e:
    print(f"Erro ao inicializar INA219: {e}")


class Application(dbus.service.Object):
    def __init__(self, bus):
        self.path = '/'
        self.services = []
        dbus.service.Object.__init__(self, bus, self.path)
        self.add_service(TestService(bus, 0, ina219))

    def get_path(self):
        return dbus.ObjectPath(self.path)

    def add_service(self, service):
        self.services.append(service)

    @dbus.service.method(DBUS_OM_IFACE, out_signature='a{oa{sa{sv}}}')
    def GetManagedObjects(self):
        response = {}
        print('GetManagedObjects')
        for service in self.services:
            response[service.get_path()] = service.get_properties()
            chrcs = service.get_characteristics()
            for chrc in chrcs:
                response[chrc.get_path()] = chrc.get_properties()
                descs = chrc.get_descriptors()
                for desc in descs:
                    response[desc.get_path()] = desc.get_properties()
        return response
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

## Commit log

2024-07-20 Escanedor de Bluetooth ReactNative
2024-07-22 servidor GATT BLE em python para o raspberry pi 5
2024-07-28 Separacao_Caracteristicas
    Codigo adaptado para separar resultados do YOLO e pytesseract em diferentes UUIDS de characters
2024-07-29 feat: Desligamento pelo App
    Função para desligar a aplicação e o sistema operacional à distancia pelo APP
2024-07-31 feat: Logica da tela de escaneamento feita
2024-08-01 feat: back end da tela de controle adicionado, faltando apenas o refinamento
2024-08-04 (fix): Corrigido atualizacao em tempo real das informacoes
    [gatt_server.py]
2024-08-04 (fix): Arrumado confusao entre a nao deteccao e o nao funcionamento do servidor
    [gatt_server_executable.py]
2024-08-04 feat: Adicionado funcionalidades de falas do app
2024-08-11 fix: correcao da funcao de desligar
2024-08-11 feat: Adicionada funcionalidade de recuperar e enviar dados da bateria do Raspberry PI
2024-08-11 feat: Adicionado código para estimar tempo de funcionamento
2024-08-11 Refactor: Nova forma de passar os valores da bateria
2024-08-11 feat: Adição da funcionalidade de monitoramento da bateria
2024-08-12 perf: Melhorado sistema de navegação
2024-09-04 fix: Compatibilizando o código com ubuntu server.
    [gatt_server_executable.py]
2024-09-04 feat: Arquivos de inicializacao automatica
2024-09-18 Arrumado erro de portugues
2024-09-18 fix: Arrumado varios problemas na lógica de algumas funções e consertado erros de acessibilidade/design
2024-09-21 Refactor: Mudado alguns parametros e mudancao de imagem/fontes
2024-09-22 feat: Adicionado termos e condições para uso do app
2024-09-23 fix: Modified device scanning logic.
2024-09-24 refactor: otimizacao de codigo
2024-09-24 Refactor: ups e lista de objetos detectaveis
2024-09-24 fix: Removed duplicate code on scanned devices
2024-10-15 fix: Arrumada fórmula de tempo estimado de duração
    [gatt_server.py]
2024-10-15 fix: Tratamento de erro adicionado
2024-10-26 feat: Adicionada as cases
    [CaseCorpo.stl, TampaCase.stl]
2024-10-28 fix: Corrigido erro de nao poder definir intervalo para 0
2024-11-01 update readme: lista de diagramas
